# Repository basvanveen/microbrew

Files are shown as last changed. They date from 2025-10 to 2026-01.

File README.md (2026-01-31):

# MicroBrew: simple ESP32/MicroPython powered brew logic

As a hobby I like to brew beer every now and then, to mash/cook i rely on my BrewMonk 
and to keep temperature i used to have an InkBird to on/off my cooling chambre(fridge).

I thought it would be fun to make my own one and integrate hydrometer/gravity metrics with it
since i recently bought a "rapt pill" to measure real time specific gravity. The Rapt Pill normally
only operates with the companies cloud infra/dashboard, so I was also curious if i could figure out
how to capture and store this data myself using micropython and an esp32 specifically.

I scraped together some left over parts/power-outlets/relays and soldered 🪛 together the necessary 
components on a prototyping board. I ended up creating a simple API driven controller, and thought
it would be useful for others to use as well. This is by no means a fully fledged solution, but it
might be a good starting point to start tinkering yourself or save you the rapt pill reverse engineering
headaches 😅.

Third Party libraries like [microdot](https://github.com/miguelgrinberg/microdot) not written by me but were very useful! ❤️

<p align="center">
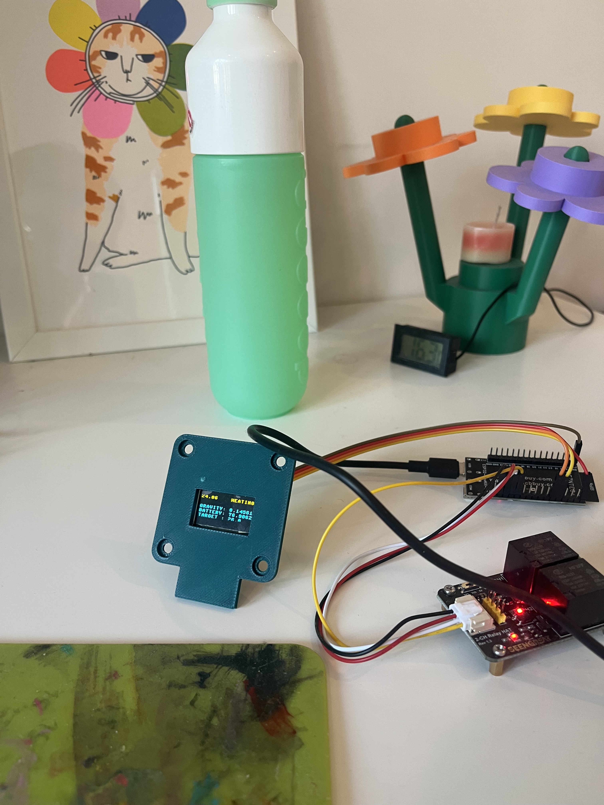
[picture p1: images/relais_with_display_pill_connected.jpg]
relais and esp
  
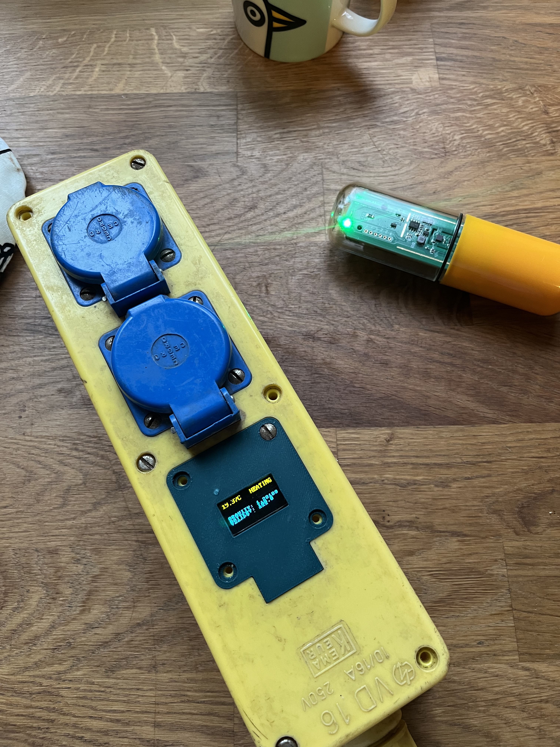
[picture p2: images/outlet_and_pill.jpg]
outletbox
  

</p>
<p align="center">

## Capabilities

- Control heating
- Control cooling
- Read current gravity realtime from Rapt using BLE
- Specify target temperature
- Simple hysteresis control
- Configuration through API
- Read Metrics through API (grafana/prometheus)
- Bluetooth metrics exposing (gravity,temperature,battery-level and rssi)
- Debug mode capability / run without actual sensor input

-- <s>TODO</s> DONE Q4 '25  -- 
- Integrate Oled status screen (SSD1306)
- Create more minimal/nicer enclosure/casing

<a href="stl/square-5mm-edges-with-outerside-and-holes-and-display-hole-indented-with-display-holes.stl">OLED INLAY DESIGN 3D/STL FILE HERE</a>

## Configuration

### WIFI

Change `wireless.json` inside the `settings` directory, and specify your AP SSID and PASSWORD like this;

```json
{
    "SSID": "SSID_GOES_HERE",
    "PASSWORD": "PASSWORD_GOES_HERE"
}
```

### HARDWARE\SENSOR specific

Change `profile.json` inside the `settings` directory, and specify the needed values ;

```json
{
    "temperatureMode": "target",   
    "temperatureUnit": "celsius",
    "temperatureSensor": "raptpill",
    "thermalState": "OFF",
    "targetTemperature": 20,
    "coolingPin": 3,
    "heatingPin": 2,
    "hysteresis": 0.5
}
```

This is pretty statically tied into my hardware setup but I will explain the configuration KEYs :

```yaml
temperatureMode : can be either `manual` or `target`
temperatureUnit : can be either `celsius` or `fahrenheit`
temperatureSensor : is now pinned to the `raptpill` sensor but in theory any temp sensor can be used *WIP*
thermalState : can be either `ON` or `OFF`, default heating state adhered when using `manual` Mode
targetTemperature: fermentation temperature float(), uses `temperatureUnit`
coolingPin : specific PIN.OUT on controller-relay to power on chambre/fridge
heatingPin : specific PIN.OUT on controller-relay to power on heating inside chambre/fridge
hysteresis : Allowed deviation during cooling/warming, to avoid continual state changes.
```

## API

Currently I exposed `3` api routes, one where you can do a `POST` call to set/change specific key-values under `/control` and two
mainly to retrieve metrics under `/metrics` and `/prometheus` that last one specifically if you want to use a Prometheus to Scrape the metrics.

### examples

POST `/control`
```bash
curl -H "Content-Type: application/json" -X POST -d '{ "targetTemperature":22,"hysteresis":0.5}' http://CONTROLLER_IP/control
```

GET `/metrics`
```bash
curl http://CONTROLLER_IP/metrics | jq
```
example output:
```bash
➜  ~ curl --silent http://192.168.10.123/metrics | jq
{
  "heatingPin": 2,
  "currentGravity": 1.23873,
  "yAxis": -239.625,
  "ReceivedSignalStrength": -59,
  "coolingPin": 3,
  "zAxis": 1024.5,
  "targetTemperature": 20,
  "temperatureUnit": "celsius",
  "batteryPercentage": 77.69922,
  "currentTemperature": 18.06094,
  "thermalState": "HEATING",
  "xAxis": 67.75,
  "temperatureSensor": "raptpill",
  "hysteresis": 0.5,
  "temperatureMode": "target"
}
```

## HARDWARE/IMPRESSION PICS 📸

<p align="center">
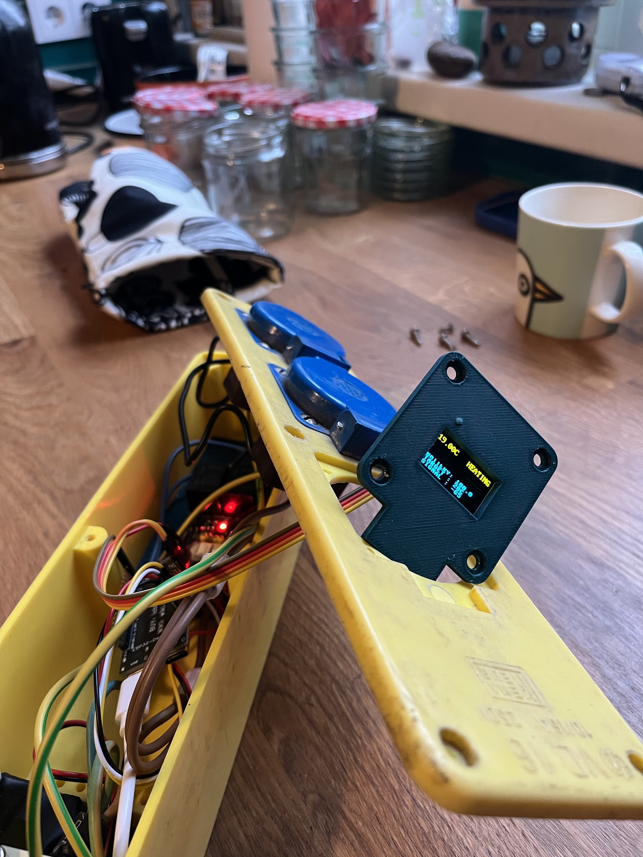
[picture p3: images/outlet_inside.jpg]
esp inside box with relays
  
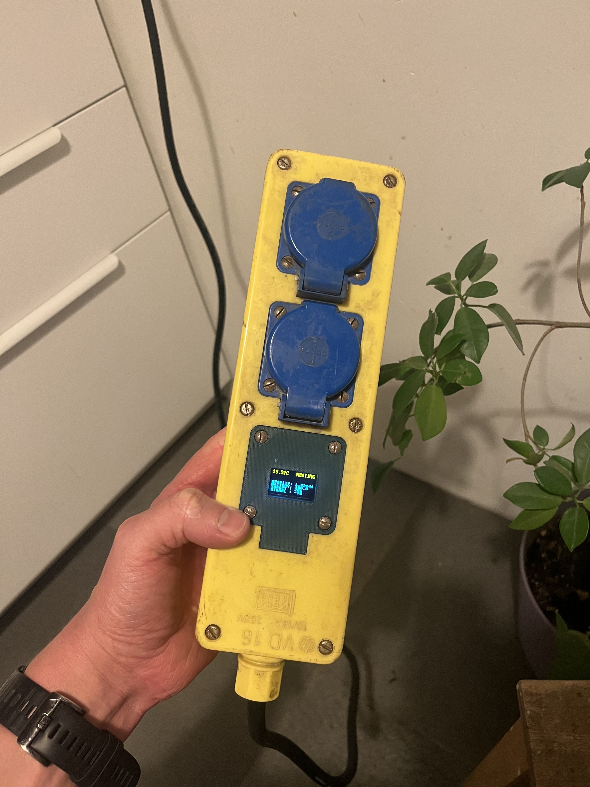
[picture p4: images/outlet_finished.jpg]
  
<p align="center">
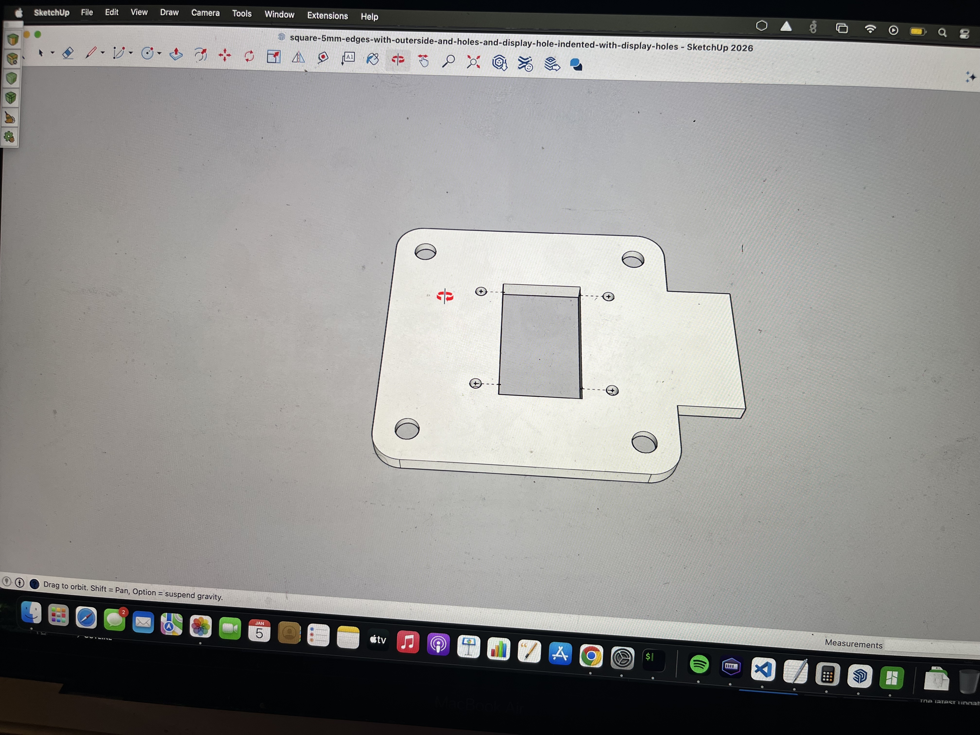
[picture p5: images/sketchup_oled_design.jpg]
sketchup mini oled frame design
  
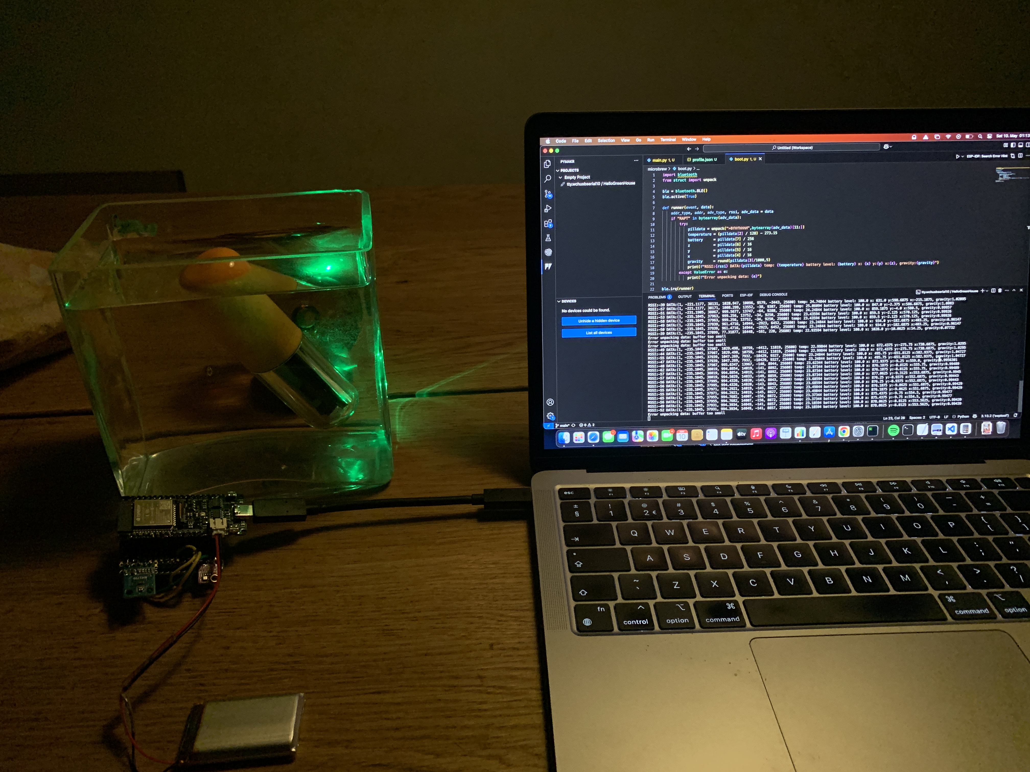
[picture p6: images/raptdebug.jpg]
pill debug in water
  
  </p>
</p>
<p align="center">
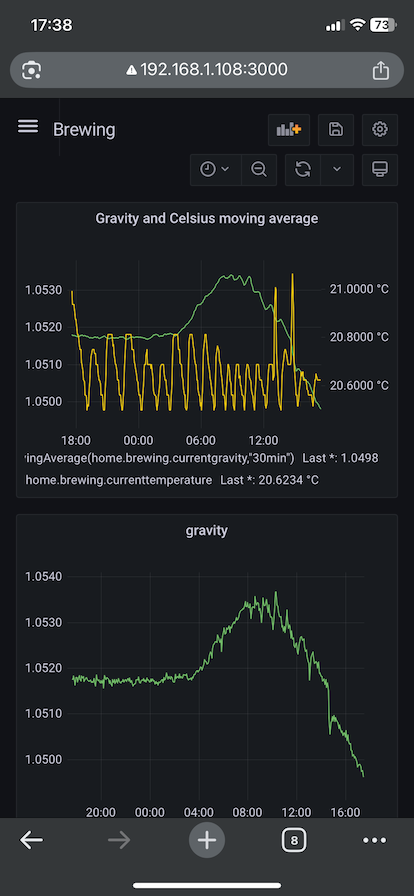
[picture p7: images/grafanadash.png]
grafana dash
    
</p>

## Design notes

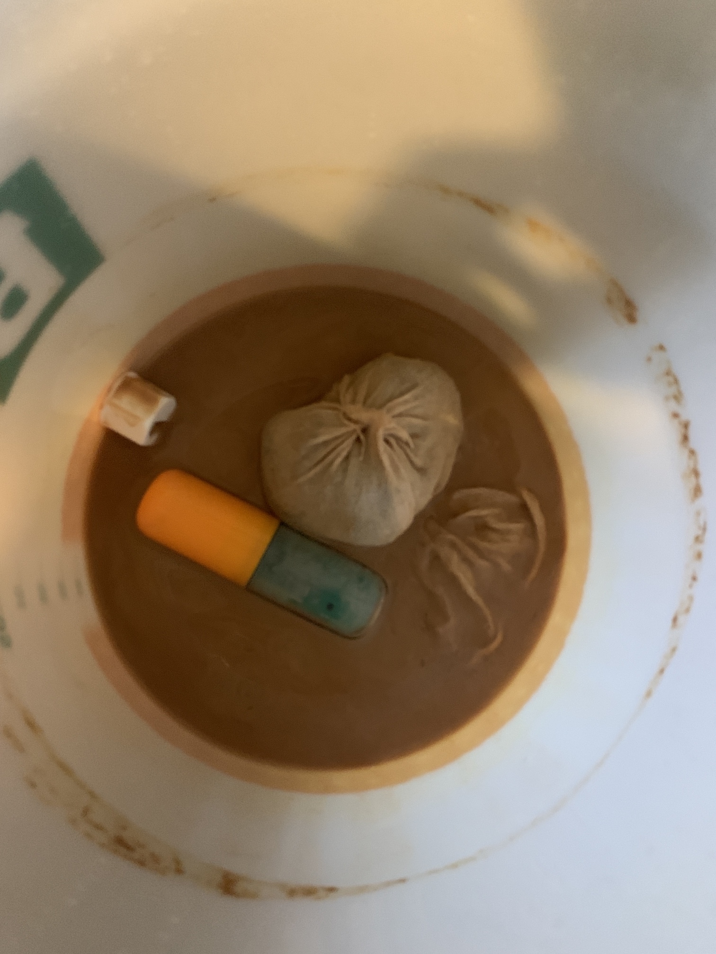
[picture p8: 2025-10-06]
images/afterfermentation.JPG

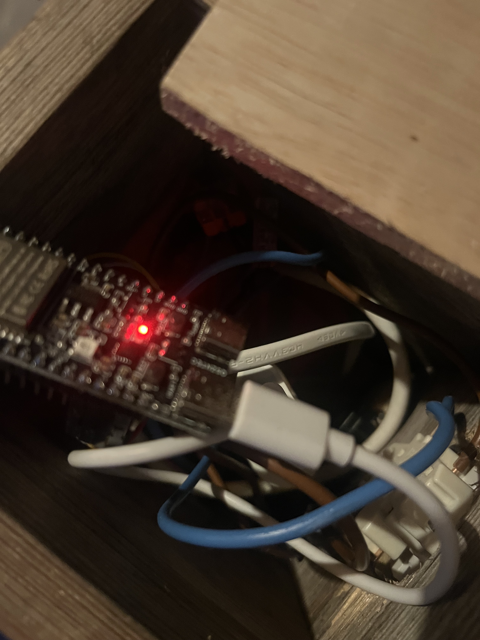
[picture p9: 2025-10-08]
images/insidebox.jpg

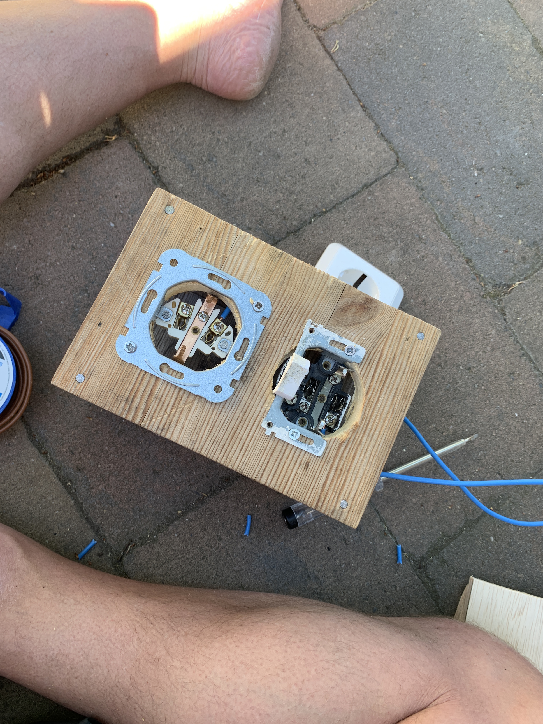
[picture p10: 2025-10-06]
images/tinkering.JPG

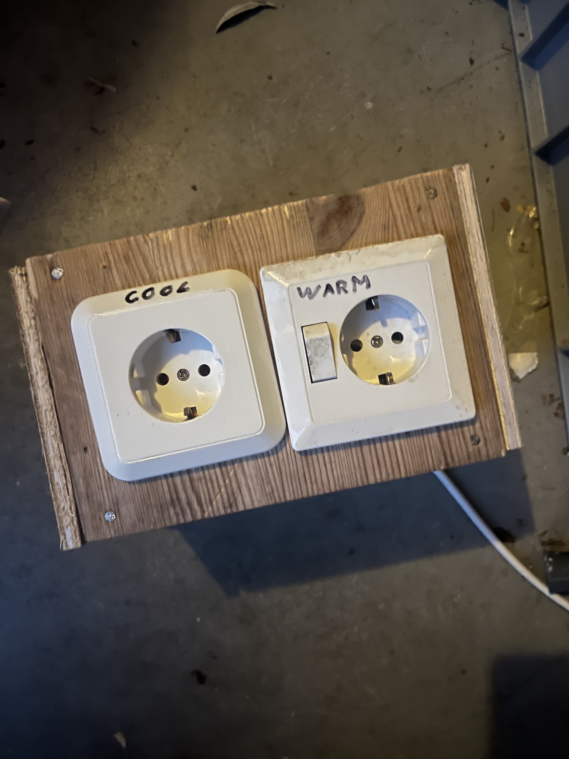
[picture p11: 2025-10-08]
images/simpleoutletbox.jpg

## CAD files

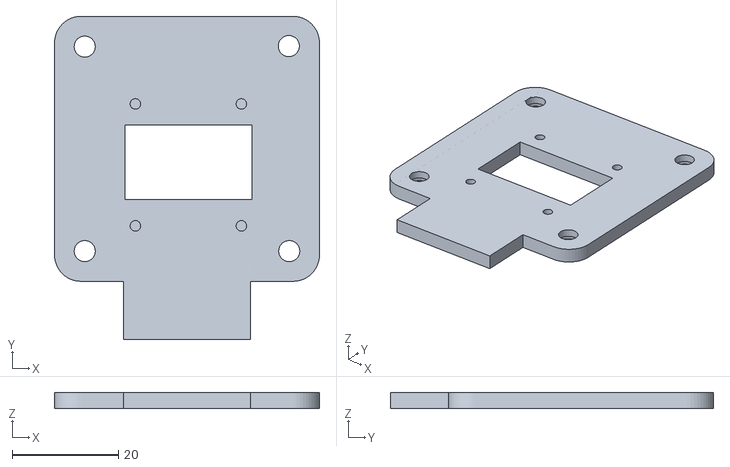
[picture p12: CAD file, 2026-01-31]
stl/square-5mm-edges-with-outerside-and-holes-and-display-hole-indented-with-display-holes.stl
50.0 x 61.0 x 3.02

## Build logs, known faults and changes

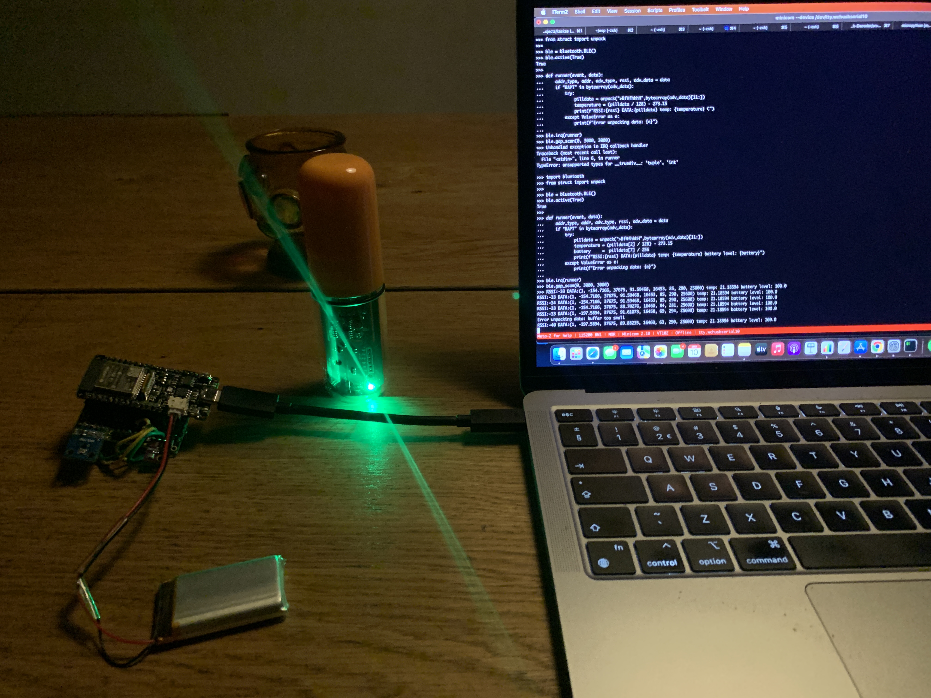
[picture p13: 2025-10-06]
images/raptdebug2.JPG

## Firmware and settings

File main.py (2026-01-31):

import sys
# adding microdot path for simpler import
sys.path.insert(1, 'microdot/')
# import display libs
sys.path.insert(1, 'libs')
import asyncio
from microdot import Microdot
from controller import MicroBrewery
import time
import sys

debugmode = False

app = Microdot()
controller = MicroBrewery("microbrew", debugmode )

@app.route('/')
async def index(request):
    return 'Hello, Brewery! 🍺'

@app.get('/metrics')
async def index(request):
    return controller.getMetrics()

@app.get('/prometheus')
async def index(request):
    return controller.json_to_prometheus(controller.getMetrics())

@app.post('/control')
async def control(request):
    # logic to set parameters go here
    for item, value in request.json.items():
        print(f"key:{item}, value:{value}")
        controller.setControlValue(item,value)
    return controller.getControlProfile()

async def sensorLoop():
    print("entering sensorloop")
    while True:
        if controller.getControlProfile()['temperatureSensor'] == 'raptpill':
              print(f"temp: {controller.getTemperature()}")
              await asyncio.sleep(1)
        else:
              print("pill not set")
              await asyncio.sleep(1)

async def thermalLoop():
    print("entering thermalLoop")
    while True:
        print(f"State: {controller.update_temperature()}")
        await asyncio.sleep(5)

async def displayLoop():
    print("entering displayLoop")
    while True:
        print(f"State: {controller.update_display()}")
        await asyncio.sleep(5)

async def main():
    sensor  = asyncio.create_task(sensorLoop())
    thermal = asyncio.create_task(thermalLoop())
    display = asyncio.create_task(displayLoop())
    server  = asyncio.create_task(app.run(port=80))

    # cleanup
    await asyncio.sleep(10)

asyncio.run(main())

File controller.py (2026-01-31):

import ujson as json
import time
import machine
import bluetooth
from struct import unpack
import ssd1306
import font

validTemperatureModes = ['target', 'manual']
validThermalStates = ["HEATING","COOLING","OFF"]
validtemperatureUnits = ['celsius','fahrenheit']
validStates     = ['on','off']

class MicroBrewery:

    def __init__(self, name, debugmode):
        self.debugmode = debugmode
        self.currentTemperature = 0.0 # default
        self.batteryPercentage = None
        self.xAxis = 0
        self.yAxis = 0
        self.zAxis = 0
        self.rssi = None
        self.currentGravity = None
        print(f"Instantiating MicroBrewery: {name}")
        with open('settings/profile.json', 'r') as f:
            self.controlProfile = json.load(f)
            print(json.dumps(self.controlProfile))
        if not self.debugmode:
            self.ble = bluetooth.BLE()
            print("enabling bluetooth")
            print(self.ble.active(True))
            self.doBluetoothScan()
        self.displayWidth = 128
        self.displayHeight = 64
        self.display = ssd1306.SSD1306_I2C(self.displayWidth, self.displayHeight, machine.SoftI2C(scl=machine.Pin(7), sda=machine.Pin(6)) )

    def update_display(self):
        self.display.fill(0)
        if self.controlProfile['thermalState'] is not "COOLING":
          font.Font(self.display).text(f"{self.currentTemperature:.2f}C   {self.controlProfile['thermalState']}", 0, 0, 16)
          #self.display.text(f"         {self.controlProfile['thermalState']}", 0, 6)
          #self.display.text("{:.2f}    {}".format(self.currentTemperature,self.controlProfile['thermalState']), 0, 6)
        else:
          font.Font(self.display).text(f"{self.currentTemperature:.2f}   ", 0, 0, 16)
          #self.display.text("{:.2f}   ".format(self.currentTemperature), 0, 6)
        if self.controlProfile['thermalState'] is "COOLING":
          #self.display.text(f"         {self.controlProfile['thermalState']}", 0, 16)
          font.Font(self.display).text(f"         {self.controlProfile['thermalState']}", 0, 16)

        #self.display.text(f"STATE  : {self.controlProfile['thermalState']}", 0, 16)
        self.display.text(f"GRAVITY: {self.currentGravity}", 0, 32)
        self.display.text(f"BATTERY: {self.batteryPercentage}", 0, 40)
        self.display.text(f"TARGET : {self.controlProfile['targetTemperature']}C", 0, 48)
        self.display.text(f"SIGNAL : {self.rssi}",0, 56)
        # self.display.text(f"ADDRESS: {self.ipaddr}", 0, 56)           
        self.display.show()
        return "updated"

    def update_temperature(self):
        if self.currentTemperature is None:
             return "None received"
        if self.currentTemperature < self.controlProfile['targetTemperature'] - self.controlProfile['hysteresis']:
            self.controlProfile['thermalState'] = "HEATING"
            machine.Pin(self.controlProfile['coolingPin'], machine.Pin.OUT).value(1)
            machine.Pin(self.controlProfile['heatingPin'], machine.Pin.OUT).value(0)
        elif self.currentTemperature > self.controlProfile['targetTemperature'] + self.controlProfile['hysteresis']:
            self.controlProfile['thermalState'] = "COOLING"
            machine.Pin(self.controlProfile['heatingPin'], machine.Pin.OUT).value(1)
            machine.Pin(self.controlProfile['coolingPin'], machine.Pin.OUT).value(0)
        else:
            self.controlProfile['thermalState'] = "OFF"  # Keeps the system stable within range
            machine.Pin(self.controlProfile['heatingPin'], machine.Pin.OUT).value(1)
            machine.Pin(self.controlProfile['coolingPin'], machine.Pin.OUT).value(1)

        return self.controlProfile['thermalState']

    def doBluetoothScan(self):
          """ Point to handler and start
              bluetooth GAP scan loop
          """
          self.ble.irq(self.raptHandler)
          self.ble.gap_scan(0, 3000, 3000)

    def getControlProfile(self):
        return self.controlProfile

    def getTemperature(self):
        if self.debugmode:
              return 123456 # running in debug just output a value 
        return self.currentTemperature
    
    def raptHandler(self, event, data):
        """ IRQ Handler fetching Bluetooth very simple
            approach where we check if advertised data
            contains RAPT string which is enough to unpack
            and parse the data. See rapt repo for more details:
            https://gitlab.com/rapt.io/public/-/wikis/Pill-Hydrometer-Bluetooth-Transmissions
        """
        _, _, _, rssi, adv_data = data # fetch data and received signal strength ignore the rest
        if "RAPT" in bytearray(adv_data):
            try:
                pilldata = unpack(">BfHfhhhH",bytearray(adv_data)[11:])
                if(self.controlProfile['temperatureUnit'] == "celsius"):
                    # Kelvin to Celsius
                    self.currentTemperature    = (pilldata[2] / 128) - 273.15
                else:
                    # Kelvin Fahrenheit
                    self.currentTemperature    = ((pilldata[2] / 128) - 273.15) * 9/5 +32
                self.batteryPercentage     = pilldata[7] / 256
                self.zAxis                 = pilldata[6] / 16
                self.yAxis                 = pilldata[5] / 16
                self.xAxis                 = pilldata[4] / 16
                self.currentGravity        = round(pilldata[3]/1000,5)
                self.rssi                  = rssi
            except ValueError as e:
                # Quick "fix", we sometimes get "buffer too small" we can ignore this
                print(f"Error unpacking data: {e}")

    def getTime(self):
        return f"{(time.localtime()[3]+self.offset)%24:02d}:{time.localtime()[4]:02d}"
    
    def getMetrics(self):
          metrics = self.controlProfile.copy()
          metrics['currentTemperature']      = self.currentTemperature
          metrics['batteryPercentage']      = self.batteryPercentage
          metrics['xAxis']      = self.xAxis
          metrics['yAxis']      = self.yAxis
          metrics['zAxis']      = self.zAxis
          metrics['currentGravity']      = self.currentGravity
          metrics['ReceivedSignalStrength']      = self.rssi
          
          return metrics
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
